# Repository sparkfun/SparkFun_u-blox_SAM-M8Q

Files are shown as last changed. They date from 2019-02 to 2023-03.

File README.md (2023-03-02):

SparkFun u-Blox SAM-M8Q
========================================

SparkFun u-Blox (https://www.sparkfun.com/products/15210)

[*SparkFun u-Blox SAM-M8Q (GPS-15210)*](https://www.sparkfun.com/products/15210)

The SAM-M8Q is a high quality GPS with equally impressive configurability.  We broke out the basic pins and added all the supporting circuitry to make this module even easier to use.  Additionally we've mounted the M8Q on a large ground plane to maximize reception quality.

Repository Contents
-------------------

* **/Documentation** - Data sheets, additional product information
* **/Hardware** - Eagle design files (.brd, .sch)
* **/Production** - Production panel files (.brd)

Documentation
--------------
* **[Installing an Arduino Library Guide](https://learn.sparkfun.com/tutorials/installing-an-arduino-library)** - Basic information on how to install an Arduino library.
* **[Library](https://github.com/sparkfun/SparkFun_u-blox_GNSS_Arduino_Library)** - Arduino Library used with the SparkFun SAM-M8Q 
* **[Hookup Guide](https://learn.sparkfun.com/tutorials/sparkfun-gps-breakout-zoe-m8q-and-sam-m8q-hookup-guide)** - Basic hookup guide for the SparkFun SAM-M8Q.

License Information
-------------------

This product is _**open source**_! 

Please review the LICENSE.md file for license information. 

If you have any questions or concerns on licensing, please contact technical support on our [SparkFun forums](https://forum.sparkfun.com/viewforum.php?f=152).

Distributed as-is; no warranty is given.

- Your friends at SparkFun.

_<COLLABORATION CREDIT>_

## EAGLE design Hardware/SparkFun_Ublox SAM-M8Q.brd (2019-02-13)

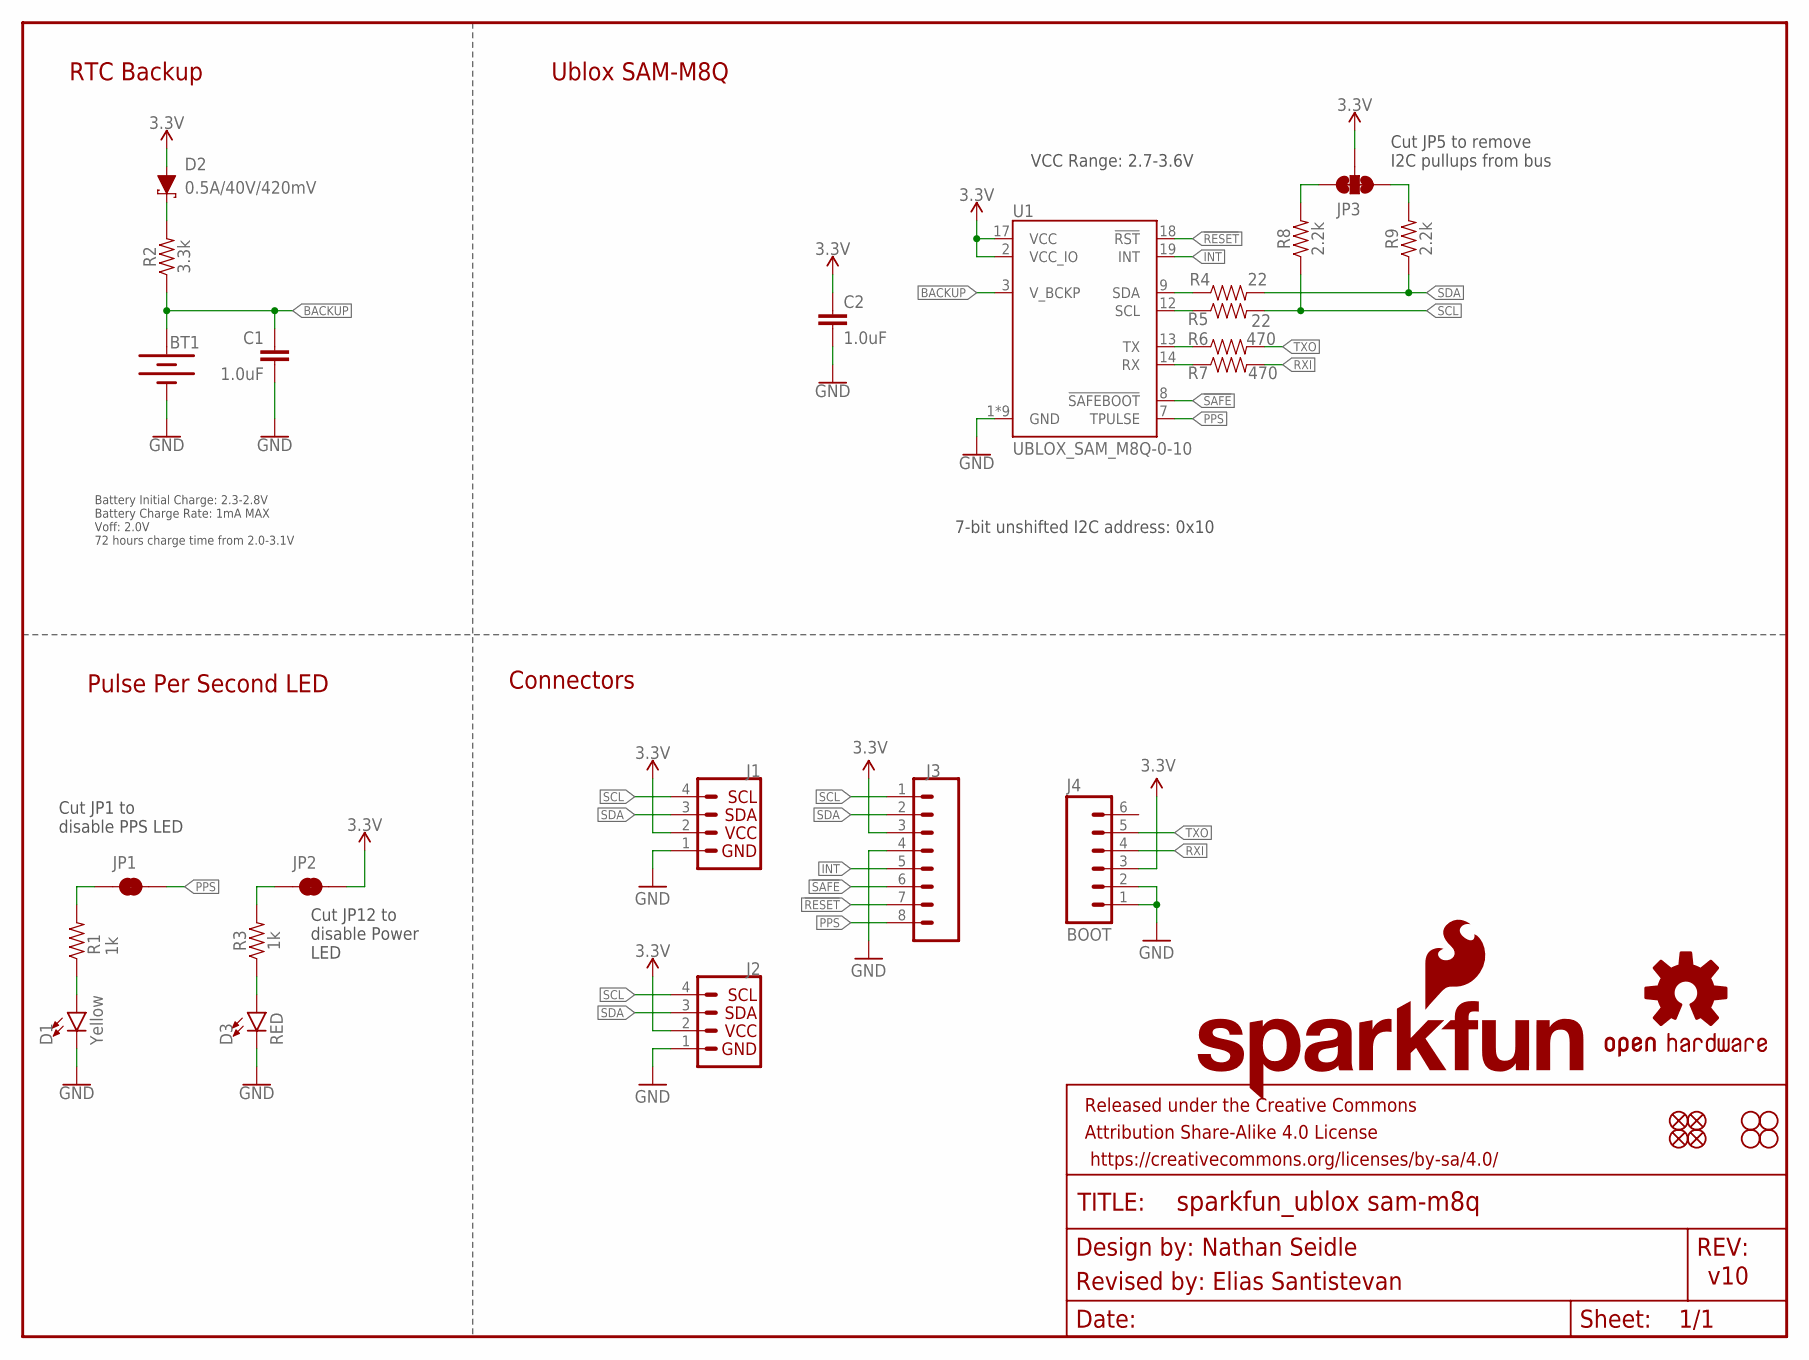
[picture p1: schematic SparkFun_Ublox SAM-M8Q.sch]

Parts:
BT1: 6.8MM_COIN_CELL; ML414H_IV01E
C1, C2: 1.0uF; 0603
D1: Yellow; LED-0603
D2: 0.5A/40V/420mV; SOD-323
D3: RED; LED-0603
FD1, FD2, FD3, FD4: FIDUCIALUFIDUCIAL; FIDUCIAL-MICRO
FRAME1: FRAME-LETTER; CREATIVE_COMMONS
H1, H2, H3, H4: STAND-OFF
J1, J2: Qwiic Right Angle; JST04_1MM_RA
J3: CONN_08NO_SILK_FEMALE_PTH; 1X08_NO_SILK
J4: BOOT; 1X06_NO_SILK
JP1, JP2: JUMPER-SMT_2_NC_TRACE_SILK; SMT-JUMPER_2_NC_TRACE_SILK
JP3: JUMPER-SMT_3_2-NC_TRACE_SILK; SMT-JUMPER_3_2-NC_TRACE_SILK
LOGO1: SFE_LOGO_NAME_FLAME.2_INCH; SFE_LOGO_NAME_FLAME_.2
LOGO2: OSHW-LOGOM; OSHW-LOGO-M
R1, R3: 1k; 0603
R2: 3.3k; 0603
R4, R5: 22; 0603
R6, R7: 470; 0603
R8, R9: 2.2k; 0603
U1: UBLOX_SAM_M8Q-0-10; SAM-M8Q

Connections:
3.3V: C2.1, D2.A, J1.2, J2.2, J3.3, J4.3, JP2.2, JP3.2, U1.2 (VCC_IO), U1.17 (VCC)
!RESET: J3.7, U1.18 (!RST)
!SAFE: J3.6, U1.8 (!SAFEBOOT)
BACKUP: BT1.+, C1.1, R2.1, U1.3 (V_BCKP)
GND: BT1.-, C1.2, C2.2, D1.C, D3.C, J1.1, J2.1, J3.4, J4.1, J4.2, U1.1 (GND), U1.4 (GND), U1.5 (GND), U1.6 (GND), U1.10 (GND), U1.11 (GND), U1.15 (GND), U1.16 (GND), U1.20 (GND)
INT: J3.5, U1.19 (INT)
unnamed: JP2.1, R3.2
unnamed: D1.A, R1.1
unnamed: D3.A, R3.1
unnamed: JP1.1, R1.2
unnamed: JP3.1, R9.2
unnamed: D2.C, R2.2
unnamed: JP3.3, R8.2
PPS: J3.8, JP1.2, U1.7 (TPULSE)
RXI: J4.4, R7.2
RXLV: R7.1, U1.14 (RX)
SCL: J1.4, J2.4, J3.1, R5.2, R8.1
SCL_LV: R5.1, U1.12 (SCL)
SDA: J1.3, J2.3, J3.2, R4.2, R9.1
SDA_LV: R4.1, U1.9 (SDA)
TXLV: R6.1, U1.13 (TX)
TXO: J4.5, R6.2

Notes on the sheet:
v10
7-bit unshifted I2C address: 0x10
Ublox SAM-M8Q
RTC Backup
Pulse Per Second LED
Cut JP5 to remove I2C pullups from bus
Cut JP1 to disable PPS LED
Revised by: Elias Santistevan
Nathan Seidle
Connectors
Cut JP12 to disable Power LED
VCC Range: 2.7-3.6V
Battery Initial Charge: 2.3-2.8V Battery Charge Rate: 1mA MAX Voff: 2.0V 72 hours charge time from 2.0-3.1V

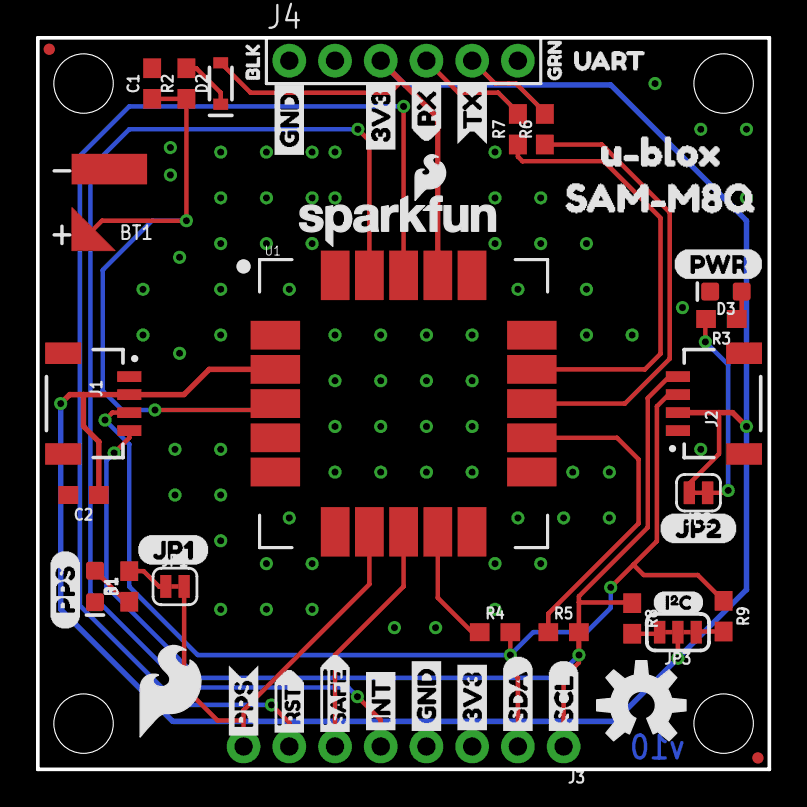
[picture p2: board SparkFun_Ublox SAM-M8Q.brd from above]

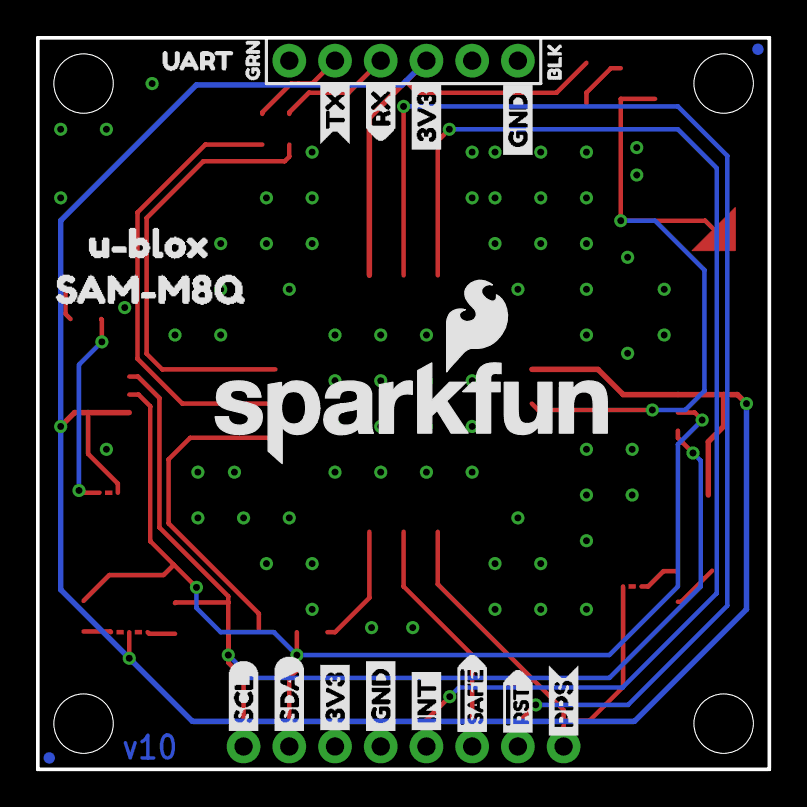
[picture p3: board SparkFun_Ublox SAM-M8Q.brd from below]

Board: 2 copper layers, 40.6 x 40.6 mm, 75 parts (20 on the bottom side), 22 nets.

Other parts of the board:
U$1, U$4: SDA-[)
U$2: SFE_LOGO_FLAME_.2
U$3, U$5: SCL-[)
U$6, U$7, U$27, U$32: 3V3-04
U$8, U$9, U$33, U$34: GND-04
U$10: I_SUPER2_C-()-03
U$11, U$45: UART0
U$12, U$13: BLK1
U$14, U$17: GRN2
U$15, U$16: INT8
U$18: JP10
U$19, U$20: RX6
U$21, U$25: SAM#M8Q4
U$22, U$26: U#BLOX3
U$23, U$24: TX7
U$28: SFE_LOGO_NAME_FLAME_.1
U$29: PPS0
U$30: PWR0
U$31: JP20
U$35, U$36: #RST3
U$39, U$40: #SAFE1
U$43, U$44: PPS5

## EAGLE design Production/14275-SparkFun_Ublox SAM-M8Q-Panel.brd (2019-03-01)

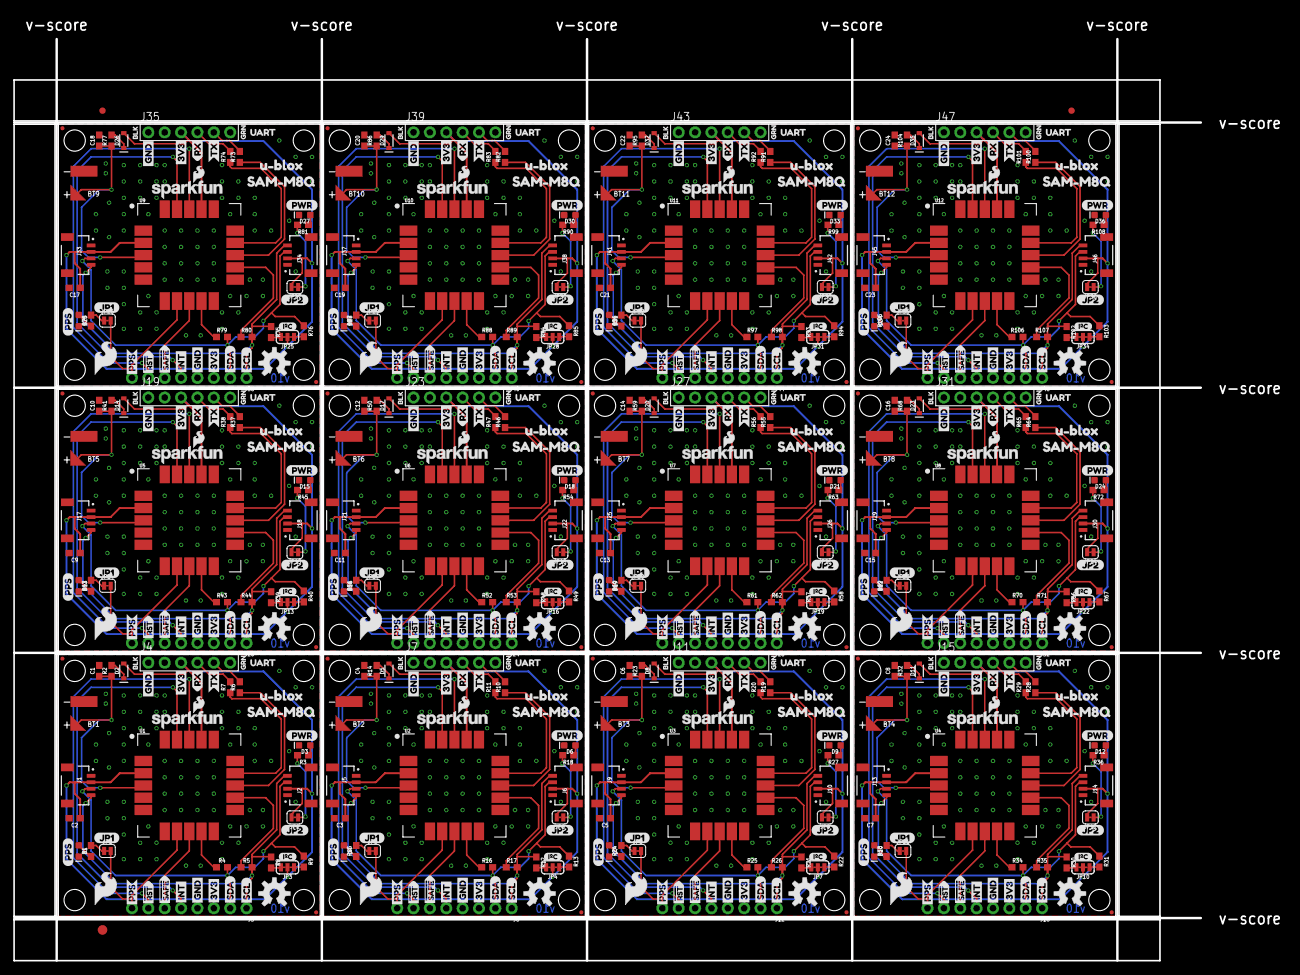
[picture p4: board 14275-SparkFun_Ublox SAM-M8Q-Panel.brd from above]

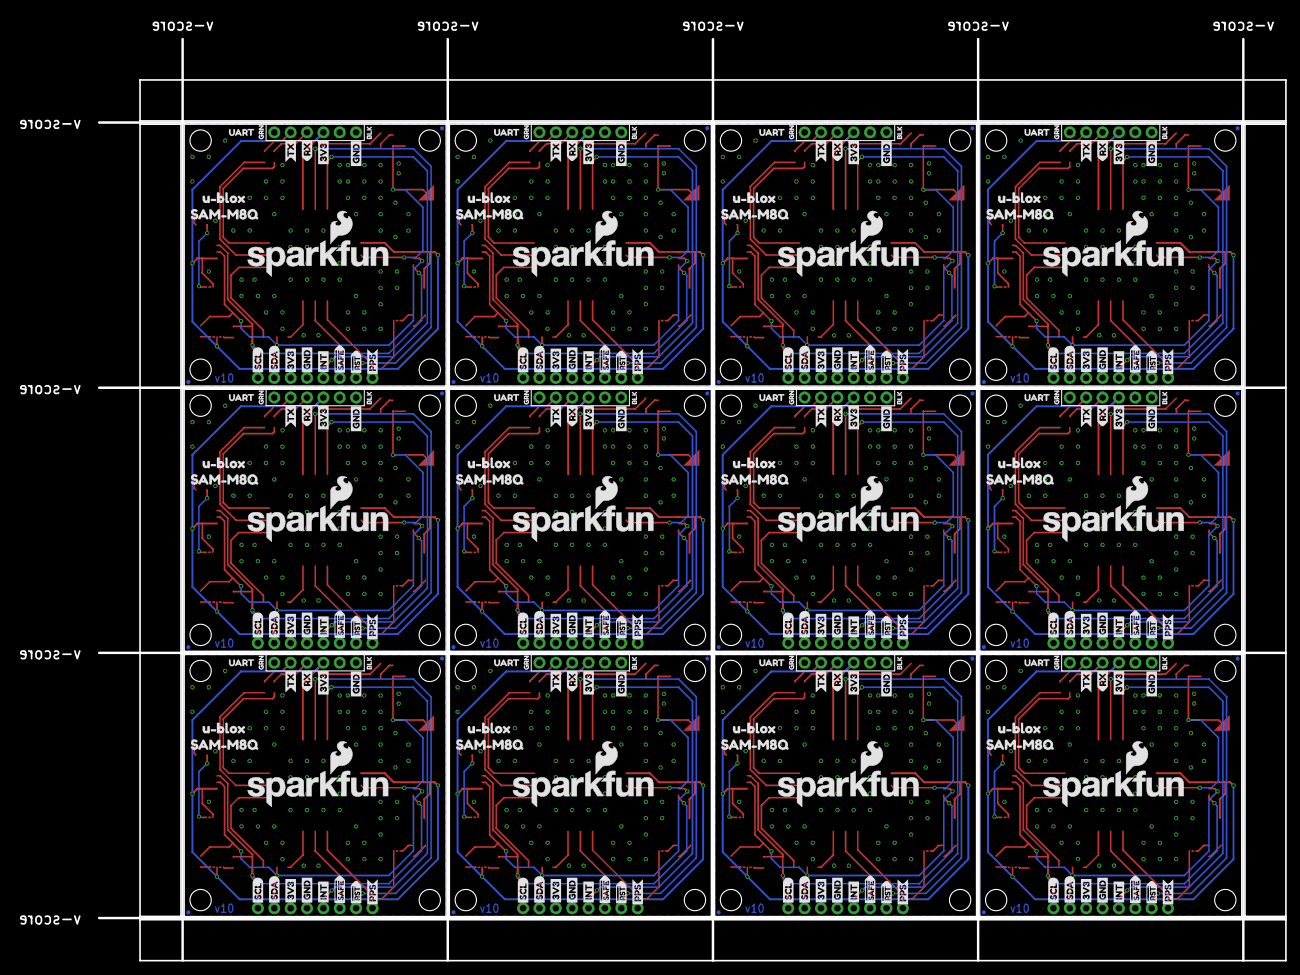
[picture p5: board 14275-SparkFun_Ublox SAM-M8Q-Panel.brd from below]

Board: 2 copper layers, 184.2 x 143.0 mm, 891 parts (240 on the bottom side), 264 nets.

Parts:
BT1, BT2, BT3, BT4, BT5, BT6, BT7, BT8, BT9, BT10, BT11, BT12: 6.8MM_COIN_CELL; ML414H_IV01E
C1, C2, C3, C4, C5, C6, C7, C8, C9, C10, C11, C12, C13, C14, C15, C16, C17, C18, C19, C20, C21, C22, C23, C24: 1.0uF; 0603
D1, D4, D7, D10, D13, D16, D19, D22, D25, D28, D31, D34: Yellow; LED-0603
D2, D5, D8, D11, D14, D17, D20, D23, D26, D29, D32, D35: 0.5A/40V/420mV; SOD-323
D3, D6, D9, D12, D15, D18, D21, D24, D27, D30, D33, D36: RED; LED-0603
E$1, E$2: FIDUCIAL-1X2
E$3: FIDUCIAL-1.5X3
FD1, FD2, FD3, FD4, FD5, FD6, FD7, FD8, FD9, FD10, FD11, FD12, FD13, FD14, FD15, FD16, FD17, FD18, FD19, FD20, FD21, FD22, FD23, FD24, FD25, FD26, FD27, FD28, FD29, FD30, FD31, FD32, FD33, FD34, FD35, FD36, FD37, FD38, FD39, FD40, FD41, FD42, FD43, FD44, FD45, FD46, FD47, FD48: FIDUCIALUFIDUCIAL; FIDUCIAL-MICRO
H1, H2, H3, H4, H5, H6, H7, H8, H9, H10, H11, H12, H13, H14, H15, H16, H17, H18, H19, H20, H21, H22, H23, H24, H25, H26, H27, H28, H29, H30, H31, H32, H33, H34, H35, H36, H37, H38, H39, H40, H41, H42, H43, H44, H45, H46, H47, H48: STAND-OFF
J1, J2, J5, J6, J9, J10, J13, J14, J17, J18, J21, J22, J25, J26, J29, J30, J33, J34, J37, J38, J41, J42, J45, J46: Qwiic Right Angle; JST04_1MM_RA
J3, J8, J12, J16, J20, J24, J28, J32, J36, J40, J44, J48: 1X08_NO_SILK
J4, J7, J11, J15, J19, J23, J27, J31, J35, J39, J43, J47: BOOT; 1X06_NO_SILK
JP1, JP5, JP8, JP11, JP14, JP17, JP20, JP23, JP26, JP29, JP32, JP35: SMT-JUMPER_2_NC_TRACE_SILK
JP2, JP6, JP9, JP12, JP15, JP18, JP21, JP24, JP27, JP30, JP33, JP36: JUMPER-SMT_2_NC_TRACE_SILK; SMT-JUMPER_2_NC_TRACE_SILK
JP3, JP4, JP7, JP10, JP13, JP16, JP19, JP22, JP25, JP28, JP31, JP34: JUMPER-SMT_3_2-NC_TRACE_SILK; SMT-JUMPER_3_2-NC_TRACE_SILK
LOGO1, LOGO4, LOGO6, LOGO8, LOGO10, LOGO12, LOGO14, LOGO16, LOGO18, LOGO20, LOGO22, LOGO24: SFE_LOGO_NAME_FLAME.2_INCH; SFE_LOGO_NAME_FLAME_.2
LOGO2, LOGO3, LOGO5, LOGO7, LOGO9, LOGO11, LOGO13, LOGO15, LOGO17, LOGO19, LOGO21, LOGO23: OSHW-LOGOM; OSHW-LOGO-M
R1, R3, R15, R18, R24, R27, R33, R36, R42, R45, R51, R54, R60, R63, R69, R72, R78, R81, R87, R90, R96, R99, R105, R108: 1k; 0603
R2, R14, R23, R32, R41, R50, R59, R68, R77, R86, R95, R104: 3.3k; 0603
R4, R5, R16, R17, R25, R26, R34, R35, R43, R44, R52, R53, R61, R62, R70, R71, R79, R80, R88, R89, R97, R98, R106, R107: 22; 0603
R6, R7, R10, R11, R19, R20, R28, R29, R37, R38, R46, R47, R55, R56, R64, R65, R73, R74, R82, R83, R91, R92, R100, R101: 470; 0603
R8, R9, R12, R13, R21, R22, R30, R31, R39, R40, R48, R49, R57, R58, R66, R67, R75, R76, R84, R85, R93, R94, R102, R103: 2.2k; 0603
U1, U2, U3, U4, U5, U6, U7, U8, U9, U10, U11, U12: UBLOX_SAM_M8Q-0-10; SAM-M8Q
U$1, U$4, U$37, U$41, U$83, U$85, U$124, U$126, U$165, U$167, U$206, U$208, U$247, U$249, U$288, U$290, U$329, U$331, U$370, U$372, U$411, U$413, U$452, U$454: SDA-[)
U$2, U$80, U$121, U$162, U$203, U$244, U$285, U$326, U$367, U$408, U$449, U$490: SFE_LOGO_FLAME_.2
U$3, U$5, U$38, U$42, U$84, U$86, U$125, U$127, U$166, U$168, U$207, U$209, U$248, U$250, U$289, U$291, U$330, U$332, U$371, U$373, U$412, U$414, U$453, U$455: SCL-[)
U$6, U$7, U$27, U$32, U$46, U$47, U$62, U$63, U$87, U$88, U$103, U$104, U$128, U$129, U$144, U$145, U$169, U$170, U$185, U$186, U$210, U$211, U$226, U$227, U$251, U$252, U$267, U$268, U$292, U$293, U$308, U$309, U$333, U$334, U$349, U$350, U$374, U$375, U$390, U$391, U$415, U$416, U$431, U$432, U$456, U$457, U$472, U$473: 3V3-04
U$8, U$9, U$33, U$34, U$48, U$49, U$64, U$65, U$89, U$90, U$105, U$106, U$130, U$131, U$146, U$147, U$171, U$172, U$187, U$188, U$212, U$213, U$228, U$229, U$253, U$254, U$269, U$270, U$294, U$295, U$310, U$311, U$335, U$336, U$351, U$352, U$376, U$377, U$392, U$393, U$417, U$418, U$433, U$434, U$458, U$459, U$474, U$475: GND-04
U$10, U$50, U$91, U$132, U$173, U$214, U$255, U$296, U$337, U$378, U$419, U$460: I_SUPER2_C-()-03
U$11, U$45, U$72, U$73, U$113, U$114, U$154, U$155, U$195, U$196, U$236, U$237, U$277, U$278, U$318, U$319, U$359, U$360, U$400, U$401, U$441, U$442, U$482, U$483: UART0
U$12, U$13, U$74, U$75, U$115, U$116, U$156, U$157, U$197, U$198, U$238, U$239, U$279, U$280, U$320, U$321, U$361, U$362, U$402, U$403, U$443, U$444, U$484, U$485: BLK1
U$14, U$17, U$76, U$77, U$117, U$118, U$158, U$159, U$199, U$200, U$240, U$241, U$281, U$282, U$322, U$323, U$363, U$364, U$404, U$405, U$445, U$446, U$486, U$487: GRN2
U$15, U$16, U$51, U$52, U$92, U$93, U$133, U$134, U$174, U$175, U$215, U$216, U$256, U$257, U$297, U$298, U$338, U$339, U$379, U$380, U$420, U$421, U$461, U$462: INT8
U$18, U$78, U$119, U$160, U$201, U$242, U$283, U$324, U$365, U$406, U$447, U$488: JP10
U$19, U$20, U$53, U$54, U$94, U$95, U$135, U$136, U$176, U$177, U$217, U$218, U$258, U$259, U$299, U$300, U$340, U$341, U$381, U$382, U$422, U$423, U$463, U$464: RX6
U$21, U$25, U$55, U$60, U$96, U$101, U$137, U$142, U$178, U$183, U$219, U$224, U$260, U$265, U$301, U$306, U$342, U$347, U$383, U$388, U$424, U$429, U$465, U$470: SAM#M8Q4
U$22, U$26, U$58, U$59, U$99, U$100, U$140, U$141, U$181, U$182, U$222, U$223, U$263, U$264, U$304, U$305, U$345, U$346, U$386, U$387, U$427, U$428, U$468, U$469: U#BLOX3
U$23, U$24, U$56, U$57, U$97, U$98, U$138, U$139, U$179, U$180, U$220, U$221, U$261, U$262, U$302, U$303, U$343, U$344, U$384, U$385, U$425, U$426, U$466, U$467: TX7
U$28, U$82, U$123, U$164, U$205, U$246, U$287, U$328, U$369, U$410, U$451, U$492: SFE_LOGO_NAME_FLAME_.1
U$29, U$61, U$102, U$143, U$184, U$225, U$266, U$307, U$348, U$389, U$430, U$471: PPS0
U$30, U$79, U$120, U$161, U$202, U$243, U$284, U$325, U$366, U$407, U$448, U$489: PWR0
U$31, U$81, U$122, U$163, U$204, U$245, U$286, U$327, U$368, U$409, U$450, U$491: JP20
U$35, U$36, U$66, U$67, U$107, U$108, U$148, U$149, U$189, U$190, U$230, U$231, U$271, U$272, U$312, U$313, U$353, U$354, U$394, U$395, U$435, U$436, U$476, U$477: #RST3
U$39, U$40, U$68, U$69, U$109, U$110, U$150, U$151, U$191, U$192, U$232, U$233, U$273, U$274, U$314, U$315, U$355, U$356, U$396, U$397, U$437, U$438, U$478, U$479: #SAFE1
U$43, U$44, U$70, U$71, U$111, U$112, U$152, U$153, U$193, U$194, U$234, U$235, U$275, U$276, U$316, U$317, U$357, U$358, U$398, U$399, U$439, U$440, U$480, U$481: PPS5

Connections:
3.3V: C2.1, D2.A, J1.2, J2.2, J3.3, J4.3, JP2.2, JP3.2, U1.2, U1.17
3.3V1: C3.1, D5.A, J5.2, J6.2, J7.3, J8.3, JP4.2, JP6.2, U2.2, U2.17
3.3V2: C5.1, D8.A, J9.2, J10.2, J11.3, J12.3, JP7.2, JP9.2, U3.2, U3.17
3.3V3: C7.1, D11.A, J13.2, J14.2, J15.3, J16.3, JP10.2, JP12.2, U4.2, U4.17
3.3V4: C9.1, D14.A, J17.2, J18.2, J19.3, J20.3, JP13.2, JP15.2, U5.2, U5.17
3.3V5: C11.1, D17.A, J21.2, J22.2, J23.3, J24.3, JP16.2, JP18.2, U6.2, U6.17
3.3V6: C13.1, D20.A, J25.2, J26.2, J27.3, J28.3, JP19.2, JP21.2, U7.2, U7.17
3.3V7: C15.1, D23.A, J29.2, J30.2, J31.3, J32.3, JP22.2, JP24.2, U8.2, U8.17
3.3V8: C17.1, D26.A, J33.2, J34.2, J35.3, J36.3, JP25.2, JP27.2, U9.2, U9.17
3.3V9: C19.1, D29.A, J37.2, J38.2, J39.3, J40.3, JP28.2, JP30.2, U10.2, U10.17
3.3V10: C21.1, D32.A, J41.2, J42.2, J43.3, J44.3, JP31.2, JP33.2, U11.2, U11.17
3.3V11: C23.1, D35.A, J45.2, J46.2, J47.3, J48.3, JP34.2, JP36.2, U12.2, U12.17
!RESET: J3.7, U1.18
!RESET1: J8.7, U2.18
!RESET2: J12.7, U3.18
!RESET3: J16.7, U4.18
!RESET4: J20.7, U5.18
!RESET5: J24.7, U6.18
!RESET6: J28.7, U7.18
!RESET7: J32.7, U8.18
!RESET8: J36.7, U9.18
!RESET9: J40.7, U10.18
!RESET10: J44.7, U11.18
!RESET11: J48.7, U12.18
!SAFE: J3.6, U1.8
!SAFE1: J8.6, U2.8
!SAFE2: J12.6, U3.8
!SAFE3: J16.6, U4.8
!SAFE4: J20.6, U5.8
!SAFE5: J24.6, U6.8
!SAFE6: J28.6, U7.8
!SAFE7: J32.6, U8.8
!SAFE8: J36.6, U9.8
!SAFE9: J40.6, U10.8
!SAFE10: J44.6, U11.8
!SAFE11: J48.6, U12.8
BACKUP: BT1.+, C1.1, R2.1, U1.3
BACKUP1: BT2.+, C4.1, R14.1, U2.3
BACKUP2: BT3.+, C6.1, R23.1, U3.3
BACKUP3: BT4.+, C8.1, R32.1, U4.3
BACKUP4: BT5.+, C10.1, R41.1, U5.3
BACKUP5: BT6.+, C12.1, R50.1, U6.3
BACKUP6: BT7.+, C14.1, R59.1, U7.3
BACKUP7: BT8.+, C16.1, R68.1, U8.3
BACKUP8: BT9.+, C18.1, R77.1, U9.3
BACKUP9: BT10.+, C20.1, R86.1, U10.3
BACKUP10: BT11.+, C22.1, R95.1, U11.3
BACKUP11: BT12.+, C24.1, R104.1, U12.3
GND: BT1.-, C1.2, C2.2, D1.C, D3.C, J1.1, J2.1, J3.4, J4.1, J4.2, U1.1, U1.4, U1.5, U1.6, U1.10, U1.11, U1.15, U1.16, U1.20
GND1: BT2.-, C3.2, C4.2, D4.C, D6.C, J5.1, J6.1, J7.1, J7.2, J8.4, U2.1, U2.4, U2.5, U2.6, U2.10, U2.11, U2.15, U2.16, U2.20
GND2: BT3.-, C5.2, C6.2, D7.C, D9.C, J9.1, J10.1, J11.1, J11.2, J12.4, U3.1, U3.4, U3.5, U3.6, U3.10, U3.11, U3.15, U3.16, U3.20
GND3: BT4.-, C7.2, C8.2, D10.C, D12.C, J13.1, J14.1, J15.1, J15.2, J16.4, U4.1, U4.4, U4.5, U4.6, U4.10, U4.11, U4.15, U4.16, U4.20
GND4: BT5.-, C9.2, C10.2, D13.C, D15.C, J17.1, J18.1, J19.1, J19.2, J20.4, U5.1, U5.4, U5.5, U5.6, U5.10, U5.11, U5.15, U5.16, U5.20
GND5: BT6.-, C11.2, C12.2, D16.C, D18.C, J21.1, J22.1, J23.1, J23.2, J24.4, U6.1, U6.4, U6.5, U6.6, U6.10, U6.11, U6.15, U6.16, U6.20
GND6: BT7.-, C13.2, C14.2, D19.C, D21.C, J25.1, J26.1, J27.1, J27.2, J28.4, U7.1, U7.4, U7.5, U7.6, U7.10, U7.11, U7.15, U7.16, U7.20
GND7: BT8.-, C15.2, C16.2, D22.C, D24.C, J29.1, J30.1, J31.1, J31.2, J32.4, U8.1, U8.4, U8.5, U8.6, U8.10, U8.11, U8.15, U8.16, U8.20
GND8: BT9.-, C17.2, C18.2, D25.C, D27.C, J33.1, J34.1, J35.1, J35.2, J36.4, U9.1, U9.4, U9.5, U9.6, U9.10, U9.11, U9.15, U9.16, U9.20
GND9: BT10.-, C19.2, C20.2, D28.C, D30.C, J37.1, J38.1, J39.1, J39.2, J40.4, U10.1, U10.4, U10.5, U10.6, U10.10, U10.11, U10.15, U10.16, U10.20
GND10: BT11.-, C21.2, C22.2, D31.C, D33.C, J41.1, J42.1, J43.1, J43.2, J44.4, U11.1, U11.4, U11.5, U11.6, U11.10, U11.11, U11.15, U11.16, U11.20
GND11: BT12.-, C23.2, C24.2, D34.C, D36.C, J45.1, J46.1, J47.1, J47.2, J48.4, U12.1, U12.4, U12.5, U12.6, U12.10, U12.11, U12.15, U12.16, U12.20
INT: J3.5, U1.19
INT1: J8.5, U2.19
INT2: J12.5, U3.19
INT3: J16.5, U4.19
INT4: J20.5, U5.19
INT5: J24.5, U6.19
INT6: J28.5, U7.19
INT7: J32.5, U8.19
INT8: J36.5, U9.19
INT9: J40.5, U10.19
INT10: J44.5, U11.19
INT11: J48.5, U12.19
unnamed: JP2.1, R3.2
unnamed: D1.A, R1.1
unnamed: D3.A, R3.1
unnamed: JP1.1, R1.2
unnamed: JP3.1, R9.2
unnamed: D2.C, R2.2
unnamed: JP4.1, R13.2
unnamed: JP3.3, R8.2
unnamed: JP4.3, R12.2
unnamed: D4.A, R15.1
unnamed: JP5.1, R15.2
unnamed: D5.C, R14.2
unnamed: JP6.1, R18.2
unnamed: D6.A, R18.1
unnamed: JP7.1, R22.2
unnamed: JP7.3, R21.2
unnamed: D7.A, R24.1
unnamed: JP8.1, R24.2
unnamed: D8.C, R23.2
unnamed: JP9.1, R27.2
unnamed: D9.A, R27.1
unnamed: JP10.1, R31.2
unnamed: JP10.3, R30.2
unnamed: D10.A, R33.1
unnamed: JP11.1, R33.2
unnamed: D11.C, R32.2
unnamed: JP12.1, R36.2
unnamed: D12.A, R36.1
unnamed: JP13.1, R40.2
unnamed: JP13.3, R39.2
unnamed: D13.A, R42.1
unnamed: JP14.1, R42.2
unnamed: D14.C, R41.2
unnamed: JP15.1, R45.2
unnamed: D15.A, R45.1
unnamed: JP16.1, R49.2
unnamed: JP16.3, R48.2
unnamed: D16.A, R51.1
unnamed: JP17.1, R51.2
unnamed: D17.C, R50.2
unnamed: JP18.1, R54.2
unnamed: D18.A, R54.1
unnamed: JP19.1, R58.2
unnamed: JP19.3, R57.2
unnamed: D19.A, R60.1
unnamed: JP20.1, R60.2
unnamed: D20.C, R59.2
unnamed: JP21.1, R63.2
unnamed: D21.A, R63.1
unnamed: JP22.1, R67.2
unnamed: JP22.3, R66.2
unnamed: D22.A, R69.1
unnamed: JP23.1, R69.2
unnamed: D23.C, R68.2
unnamed: JP24.1, R72.2
unnamed: D24.A, R72.1
unnamed: JP25.1, R76.2
unnamed: JP25.3, R75.2
unnamed: D25.A, R78.1
unnamed: JP26.1, R78.2
unnamed: D26.C, R77.2
unnamed: JP27.1, R81.2
unnamed: D27.A, R81.1
unnamed: JP28.1, R85.2
unnamed: JP28.3, R84.2
unnamed: D28.A, R87.1
unnamed: JP29.1, R87.2
unnamed: D29.C, R86.2
unnamed: JP30.1, R90.2
unnamed: D30.A, R90.1
unnamed: JP31.1, R94.2
unnamed: JP31.3, R93.2
unnamed: D31.A, R96.1
unnamed: JP32.1, R96.2
unnamed: D32.C, R95.2
unnamed: JP33.1, R99.2
unnamed: D33.A, R99.1
unnamed: JP34.1, R103.2
unnamed: JP34.3, R102.2
unnamed: D34.A, R105.1
unnamed: JP35.1, R105.2
unnamed: D35.C, R104.2
unnamed: JP36.1, R108.2
unnamed: D36.A, R108.1
PPS: J3.8, JP1.2, U1.7
PPS1: J8.8, JP5.2, U2.7
PPS2: J12.8, JP8.2, U3.7
PPS3: J16.8, JP11.2, U4.7
PPS4: J20.8, JP14.2, U5.7
PPS5: J24.8, JP17.2, U6.7
PPS6: J28.8, JP20.2, U7.7
PPS7: J32.8, JP23.2, U8.7
PPS8: J36.8, JP26.2, U9.7
PPS9: J40.8, JP29.2, U10.7
PPS10: J44.8, JP32.2, U11.7
PPS11: J48.8, JP35.2, U12.7
RXI: J4.4, R7.2
RXI1: J7.4, R11.2
RXI2: J11.4, R20.2
RXI3: J15.4, R29.2
RXI4: J19.4, R38.2
RXI5: J23.4, R47.2
RXI6: J27.4, R56.2
RXI7: J31.4, R65.2
RXI8: J35.4, R74.2
RXI9: J39.4, R83.2
RXI10: J43.4, R92.2
RXI11: J47.4, R101.2
RXLV: R7.1, U1.14
RXLV1: R11.1, U2.14
RXLV2: R20.1, U3.14
RXLV3: R29.1, U4.14
RXLV4: R38.1, U5.14
RXLV5: R47.1, U6.14
RXLV6: R56.1, U7.14
RXLV7: R65.1, U8.14
RXLV8: R74.1, U9.14
RXLV9: R83.1, U10.14
RXLV10: R92.1, U11.14
RXLV11: R101.1, U12.14
SCL: J1.4, J2.4, J3.1, R5.2, R8.1
SCL1: J5.4, J6.4, J8.1, R12.1, R17.2
SCL2: J9.4, J10.4, J12.1, R21.1, R26.2
SCL3: J13.4, J14.4, J16.1, R30.1, R35.2
SCL4: J17.4, J18.4, J20.1, R39.1, R44.2
SCL5: J21.4, J22.4, J24.1, R48.1, R53.2
SCL6: J25.4, J26.4, J28.1, R57.1, R62.2
SCL7: J29.4, J30.4, J32.1, R66.1, R71.2
SCL8: J33.4, J34.4, J36.1, R75.1, R80.2
SCL9: J37.4, J38.4, J40.1, R84.1, R89.2
SCL10: J41.4, J42.4, J44.1, R93.1, R98.2
SCL11: J45.4, J46.4, J48.1, R102.1, R107.2
SCL_LV: R5.1, U1.12
SCL_LV1: R17.1, U2.12
SCL_LV2: R26.1, U3.12
SCL_LV3: R35.1, U4.12
SCL_LV4: R44.1, U5.12
SCL_LV5: R53.1, U6.12
SCL_LV6: R62.1, U7.12
SCL_LV7: R71.1, U8.12
SCL_LV8: R80.1, U9.12
SCL_LV9: R89.1, U10.12
SCL_LV10: R98.1, U11.12
SCL_LV11: R107.1, U12.12
SDA: J1.3, J2.3, J3.2, R4.2, R9.1
SDA1: J5.3, J6.3, J8.2, R13.1, R16.2
SDA2: J9.3, J10.3, J12.2, R22.1, R25.2
SDA3: J13.3, J14.3, J16.2, R31.1, R34.2
SDA4: J17.3, J18.3, J20.2, R40.1, R43.2
SDA5: J21.3, J22.3, J24.2, R49.1, R52.2
SDA6: J25.3, J26.3, J28.2, R58.1, R61.2
SDA7: J29.3, J30.3, J32.2, R67.1, R70.2
SDA8: J33.3, J34.3, J36.2, R76.1, R79.2
SDA9: J37.3, J38.3, J40.2, R85.1, R88.2
SDA10: J41.3, J42.3, J44.2, R94.1, R97.2
SDA11: J45.3, J46.3, J48.2, R103.1, R106.2
SDA_LV: R4.1, U1.9
SDA_LV1: R16.1, U2.9
SDA_LV2: R25.1, U3.9
SDA_LV3: R34.1, U4.9
SDA_LV4: R43.1, U5.9
SDA_LV5: R52.1, U6.9
SDA_LV6: R61.1, U7.9
SDA_LV7: R70.1, U8.9
SDA_LV8: R79.1, U9.9
SDA_LV9: R88.1, U10.9
SDA_LV10: R97.1, U11.9
SDA_LV11: R106.1, U12.9
TXLV: R6.1, U1.13
TXLV1: R10.1, U2.13
TXLV2: R19.1, U3.13
TXLV3: R28.1, U4.13
TXLV4: R37.1, U5.13
TXLV5: R46.1, U6.13
TXLV6: R55.1, U7.13
TXLV7: R64.1, U8.13
TXLV8: R73.1, U9.13
TXLV9: R82.1, U10.13
TXLV10: R91.1, U11.13
TXLV11: R100.1, U12.13
TXO: J4.5, R6.2
TXO1: J7.5, R10.2
TXO2: J11.5, R19.2
TXO3: J15.5, R28.2
TXO4: J19.5, R37.2
TXO5: J23.5, R46.2
TXO6: J27.5, R55.2
TXO7: J31.5, R64.2
TXO8: J35.5, R73.2
TXO9: J39.5, R82.2
TXO10: J43.5, R91.2
TXO11: J47.5, R100.2

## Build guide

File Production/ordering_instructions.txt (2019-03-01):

panel size, 178x137mm
PCB thickness, 1.6mm
number of layers, 2
soldermask color, Red
silkscreen color, White
oz copper, 1oz
finish, HASL lead free
stencils, none
pcs per panel, 12

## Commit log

2019-02-06 Initial Commit (see description)
    * Copies from SparkX repo
    * Changed all trace widths to 10 mil, VCC to 12 mil
    * Adds reflowable battery
    * Adjusts Schematic organization
    * Adds "Design By" and "Revised By"
    * Adds SparkFun silk
    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
    [SparkFun_Ublox SAM-M8Q.brd, SparkFun_Ublox SAM-M8Q.sch]
2019-02-06 Replaces all part with SparkFun parts, moves temp libarary parts to SparkFun Eagle libararies
    [SparkFun_Ublox SAM-M8Q.brd, SparkFun_Ublox SAM-M8Q.sch]
2019-02-06 Changes all drill sizes to 15 mil, adjust schematic labels
    [SparkFun_Ublox SAM-M8Q.brd, SparkFun_Ublox SAM-M8Q.sch]
2019-02-07 Updates GPS module with updated part, adds VCC range and Battery text to schematic
    [SparkFun_Ublox SAM-M8Q.brd, SparkFun_Ublox SAM-M8Q.sch]
2019-02-11 Changes JP12 to JP2, fixes SDA trace, adds silk on top
    [SparkFun_Ublox SAM-M8Q.brd, SparkFun_Ublox SAM-M8Q.sch]
2019-02-12 Changes polygon width to 10 mil and dimension to 8 mil
    [SparkFun_Ublox SAM-M8Q.brd, SparkFun_Ublox SAM-M8Q.sch]
2019-02-13 Adds measurments to measures layer, fixes power LED air wire, adjusts bottom dimension line
    [SparkFun_Ublox SAM-M8Q.brd]
2019-02-14 Created panel v10
    [14275-SparkFun_Ublox SAM-M8Q-Panel.GBL, 14275-SparkFun_Ublox SAM-M8Q-Panel.GBO, 14275-SparkFun_Ublox SAM-M8Q-Panel.GBS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]
2019-03-27 Updates address to correct default and only: 0x42
    [SparkFun_Ublox SAM-M8Q.sch]

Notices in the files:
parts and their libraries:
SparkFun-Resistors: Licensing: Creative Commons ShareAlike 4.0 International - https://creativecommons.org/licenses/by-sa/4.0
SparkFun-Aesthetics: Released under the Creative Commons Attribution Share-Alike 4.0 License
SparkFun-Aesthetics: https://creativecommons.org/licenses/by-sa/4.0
